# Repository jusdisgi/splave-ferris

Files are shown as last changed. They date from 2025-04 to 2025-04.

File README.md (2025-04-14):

# splave-ferris
Simple 34-key split ergonomic keyboard running ZMK on a Seeed XIAO BLE controller and (eventually) supporting multiple switch types. Similar in layout to the Ferris Sweep except with a bit of finger splay.

My goals are to make the keyboard as small and thin as possibe while remaining comfortable, efficient, and relatively durable. That is the main rationale for not using hotswap switches; in addition to adding a bit of height, it makes the keys much less secure if you aren't using a case of some kind. I intend to plastidip the bottom and otherwise leave it raw.

The board is designed to be primarily assembled with SMD methods. I intend to use solder paste and a hotplate to surface mount the controller, button, switch, and all the diodes, leaving only the battery connector and keyswitches to manually solder. I may even experiment with doing those with a hot air rework station. In any case this is why the back is totatlly devoid of components.

At the moment I have only done the Choc v1 version, but I expect to have more soon. The layout is done in ergogen, so it's relatively easy to adapt as needed. The next switch implemented will likely be the new Kailh CPG1316S ultra-low profile scissor switch. In addition to being extremely low-profile, it is a surface-mount part; with an appropriate battery connector, I may be able to design it so it required no manual soldering at all.

I created a schematic, but while I believe it to be accurate, it is not connected to the PCB files in any way, as they were generated by ergogen.

I remain very new at all this stuff. So if you see something wrong, please let me know!






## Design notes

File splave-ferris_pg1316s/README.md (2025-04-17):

# splave-ferris_pg1316s
A version of splave-ferris using the new Kailh PG1316S Ultra-low-profile scissor switches.

For more on the splave-ferris generally, see the readme in the base directory.

There are quite a few changes from the choc version of the board. Here are the most notable I could think of:

1. Keycaps for these switches are 16x16mm, so I changed the spacing accordingly. Several other dimensions were changed as needed.
2. I changed the battery connector from a JST to a Molex Pico EZMate, which surface mounts and has a much lower profile.
3. I removed the reset button, as the XIAO has one built in and this is my most minimalist design.
4. Battery connector and power switch are in new positions.
5. I switched from SOD-123 diodes to SOD-323 due to the diode pocket on the PG1316 having only 1.2mm of headspace.
6. Everything on the board is surface mount, and nothing is on the back of the board. This one can be manufactured in a single hotplate run.
7. The routing is somewhat cleaner, despite the all-SMD design requiring a lot of vias. I think I'm getting better.

As with the choc version, this is intended to be used without a case.

I created a schematic, but while I believe it to be accurate, it is not connected to the PCB files in any way, as they were generated by ergogen. Also, the PCB files you likely want are the _left and _right versions...the one without a direction includes both halves of the board, but the nets are all the same to that may cause problems. It is also unrouted, although if you do wish to do the routing differently there are also unrouted versions of each half.

I have included production gerber files. I am planning on ordering them soon, but as yet they are untested.

I remain very new at all this stuff. So if you see something wrong, please let me know!

Here are some pics...






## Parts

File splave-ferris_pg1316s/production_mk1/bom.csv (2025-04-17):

Designator | Footprint | Quantity | Value | LCSC Part #
CONN1 | battery_connector_molex_pico_ezmate_1x02 | 1
D1, D10, D11, D12, D13, D14, D15, D16, D17, D2, D3, D4, D5, D6, D7, D8, D9 | D_SOD-323F | 17
MCU1 | xiao_smd | 1
S1, S10, S11, S12, S13, S14, S15, S16, S17, S2, S3, S4, S5, S6, S7, S8, S9 | PG1316S | 17
T1 | SPDT_C128955 | 1

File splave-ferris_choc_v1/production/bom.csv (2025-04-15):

Designator | Footprint | Quantity | Value | LCSC Part #
B1 | SW_TACT_ALPS_SKQGABE010 | 1
D1, D10, D11, D12, D13, D14, D15, D16, D17, D2, D3, D4, D5, D6, D7, D8, D9 | diode_tht_sod123 | 17
JST1 | battery_connector_jst_ph_2 | 1
MCU1 | xiao_smd | 1
T1 | SPDT_C128955 | 1

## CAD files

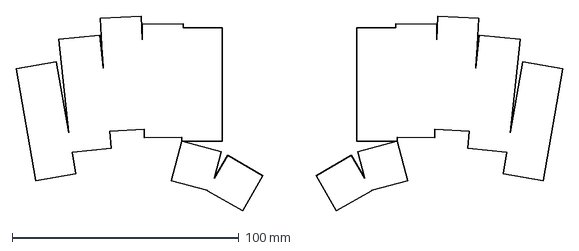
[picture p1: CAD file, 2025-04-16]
splave-ferris_pg1316s/output/outlines/raw.dxf
241.0 x 85.9 mm

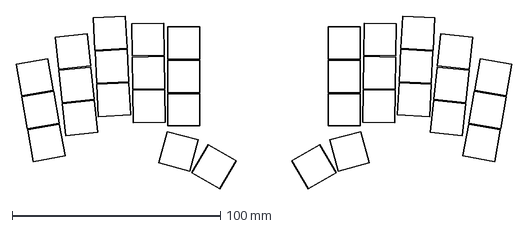
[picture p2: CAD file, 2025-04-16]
splave-ferris_pg1316s/output/outlines/keys.dxf
238.1 x 82.9 mm

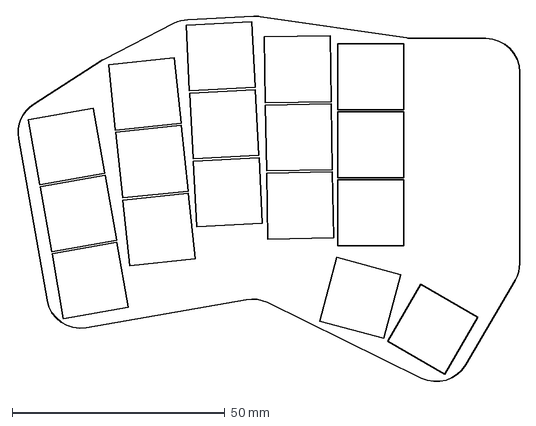
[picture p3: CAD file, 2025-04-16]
splave-ferris_pg1316s/output/outlines/combo.dxf
118.3 x 86.9 mm

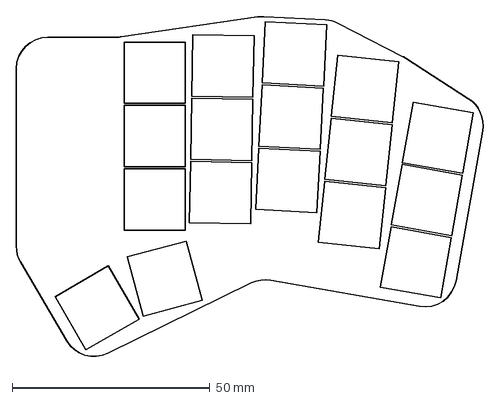
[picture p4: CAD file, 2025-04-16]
splave-ferris_pg1316s/output/outlines/combo_right.dxf
118.3 x 86.9 mm

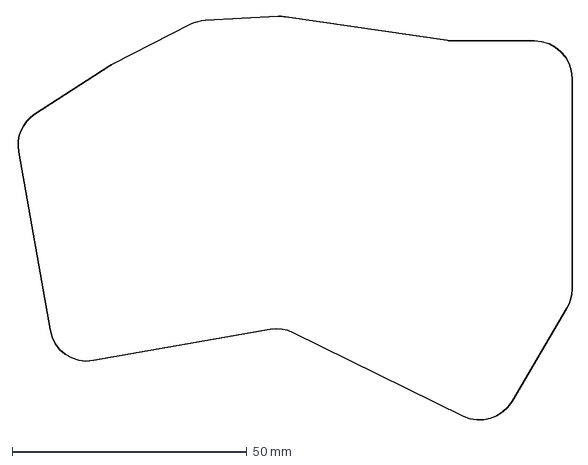
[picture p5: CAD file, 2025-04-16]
splave-ferris_pg1316s/output/outlines/board_left.dxf
118.3 x 86.9 mm

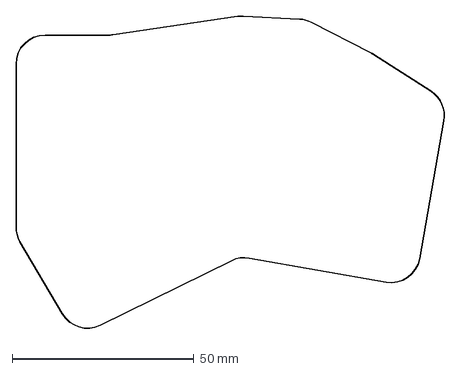
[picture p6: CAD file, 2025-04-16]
splave-ferris_pg1316s/output/outlines/board_right.dxf
118.3 x 86.9 mm

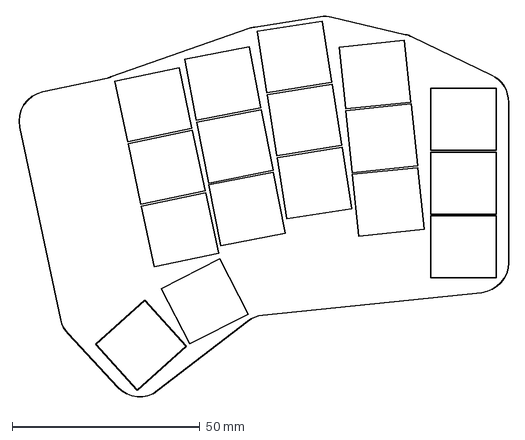
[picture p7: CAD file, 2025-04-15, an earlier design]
splave-ferris_choc_v1/output/outlines/combo_right.dxf
131.0 x 102.1 mm

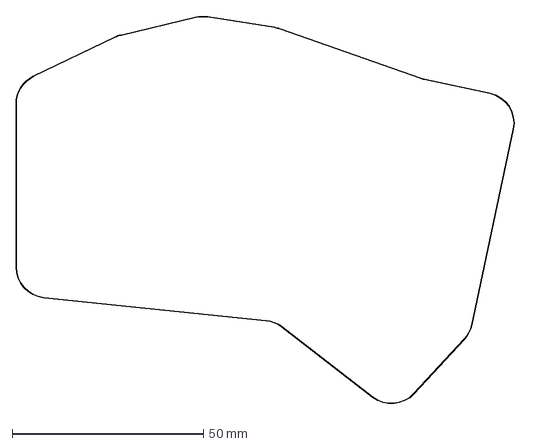
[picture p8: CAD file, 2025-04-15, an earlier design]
splave-ferris_choc_v1/output/outlines/board_left.dxf
131.0 x 102.1 mm

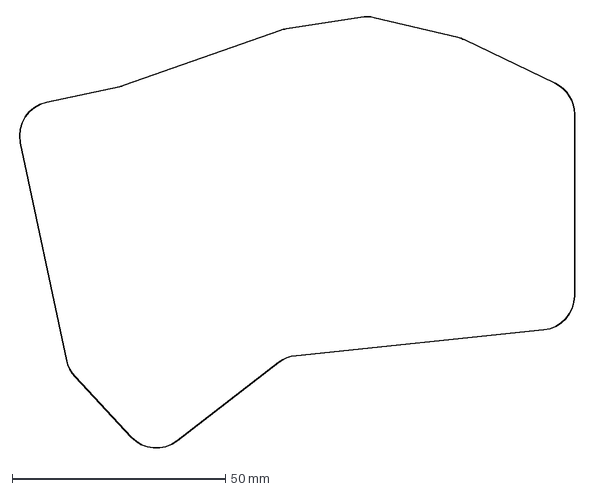
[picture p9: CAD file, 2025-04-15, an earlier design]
splave-ferris_choc_v1/output/outlines/board_right.dxf
131.0 x 102.1 mm

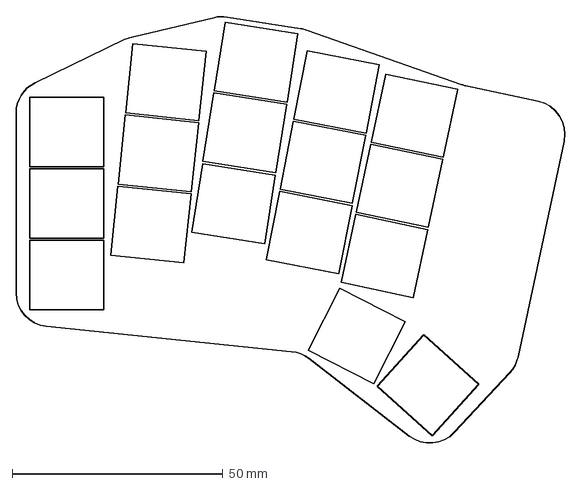
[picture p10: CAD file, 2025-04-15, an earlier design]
splave-ferris_choc_v1/output/outlines/combo.dxf
131.0 x 102.1 mm

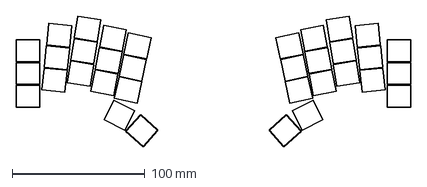
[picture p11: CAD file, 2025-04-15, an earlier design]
splave-ferris_choc_v1/output/outlines/keys.dxf
297.0 x 98.2 mm

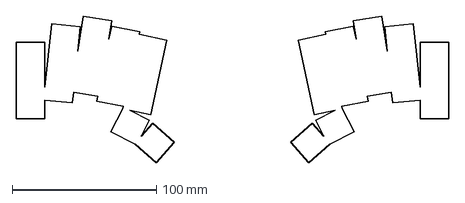
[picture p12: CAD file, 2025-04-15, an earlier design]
splave-ferris_choc_v1/output/outlines/raw.dxf
299.5 x 101.4 mm

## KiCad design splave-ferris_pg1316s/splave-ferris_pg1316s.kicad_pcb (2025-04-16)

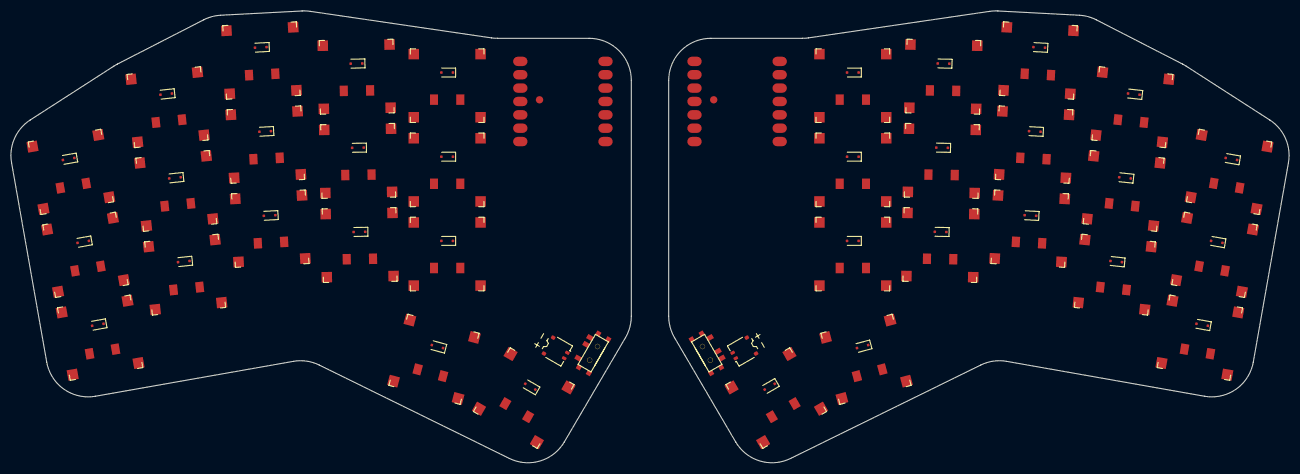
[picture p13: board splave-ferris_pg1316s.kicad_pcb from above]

Board: 2 copper layers, 242.9 x 85.9 mm, 74 parts (0 on the bottom side), 55 nets, no tracks yet.

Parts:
CONN1, CONN2: battery_connector_molex_pico_ezmate_1x02
D1, D2, D3, D4, D5, D6, D7, D8, D9, D10, D11, D12, D13, D14, D15, D16, D17, D18, D19, D20, D21, D22, D23, D24, D25, D26, D27, D28, D29, D30, D31, D32, D33, D34: D_SOD-323F
MCU1, MCU2: xiao_smd
S1, S2, S3, S4, S5, S6, S7, S8, S9, S10, S11, S12, S13, S14, S15, S16, S17, S18, S19, S20, S21, S22, S23, S24, S25, S26, S27, S28, S29, S30, S31, S32, S33, S34: PG1316S
T1, T2: SPDT_C128955

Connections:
BAT: MCU1.19, MCU2.19, T1.2, T2.1
BAT_P: CONN1.2, CONN2.2, T1.1, T2.2
CLK: MCU1.15, MCU2.15
D0: D3.2, D6.2, D9.2, D12.2, D15.2, D33.2, D34.2, MCU1.1, MCU2.1
D1: MCU1.2, MCU2.2, S7.2, S8.2, S9.2, S30.2, S31.2, S32.2, S34.2
D2: D2.2, D5.2, D8.2, D11.2, D14.2, MCU1.3, MCU2.3, S27.2, S28.2, S29.2, S33.2
D3: MCU1.4, MCU2.4, S4.2, S5.2, S6.2, S18.2, S19.2, S20.2
D4: D1.2, D4.2, D7.2, D10.2, D13.2, D18.2, D21.2, D24.2, D27.2, D30.2, MCU1.5, MCU2.5
D5: MCU1.6, MCU2.6, S1.2, S2.2, S3.2, S21.2, S22.2, S23.2
D6: MCU1.7, MCU2.7
D7: MCU1.8, MCU2.8
D8: D19.2, D22.2, D25.2, D28.2, D31.2, MCU1.9, MCU2.9, S10.2, S11.2, S12.2, S16.2
D9: D16.2, D17.2, MCU1.10, MCU2.10, S24.2, S25.2, S26.2
D10: D20.2, D23.2, D26.2, D29.2, D32.2, MCU1.11, MCU2.11, S13.2, S14.2, S15.2, S17.2
DIO: MCU1.16, MCU2.16
GND: CONN1.1, CONN2.1, MCU1.13, MCU1.18, MCU1.20, MCU2.13, MCU2.18, MCU2.20
NFC1: MCU1.21, MCU2.21
NFC2: MCU1.22, MCU2.22
RAW3V3: MCU1.12, MCU2.12
RAW5V: MCU1.14, MCU2.14
RST: MCU1.17, MCU2.17
far_fan: D17.1, S17.1
index_bottom: D10.1, S10.1
index_home: D11.1, S11.1
index_top: D12.1, S12.1
inner_bottom: D13.1, S13.1
inner_home: D14.1, S14.1
inner_top: D15.1, S15.1
middle_bottom: D7.1, S7.1
middle_home: D8.1, S8.1
middle_top: D9.1, S9.1
mirror_far_fan: D34.1, S34.1
mirror_index_bottom: D27.1, S27.1
mirror_index_home: D28.1, S28.1
mirror_index_top: D29.1, S29.1
mirror_inner_bottom: D30.1, S30.1
mirror_inner_home: D31.1, S31.1
mirror_inner_top: D32.1, S32.1
mirror_middle_bottom: D24.1, S24.1
mirror_middle_home: D25.1, S25.1
mirror_middle_top: D26.1, S26.1
mirror_near_fan: D33.1, S33.1
mirror_pinky_bottom: D18.1, S18.1
mirror_pinky_home: D19.1, S19.1
mirror_pinky_top: D20.1, S20.1
mirror_ring_bottom: D21.1, S21.1
mirror_ring_home: D22.1, S22.1
mirror_ring_top: D23.1, S23.1
near_fan: D16.1, S16.1
pinky_bottom: D1.1, S1.1
pinky_home: D2.1, S2.1
pinky_top: D3.1, S3.1
ring_bottom: D4.1, S4.1
ring_home: D5.1, S5.1
ring_top: D6.1, S6.1

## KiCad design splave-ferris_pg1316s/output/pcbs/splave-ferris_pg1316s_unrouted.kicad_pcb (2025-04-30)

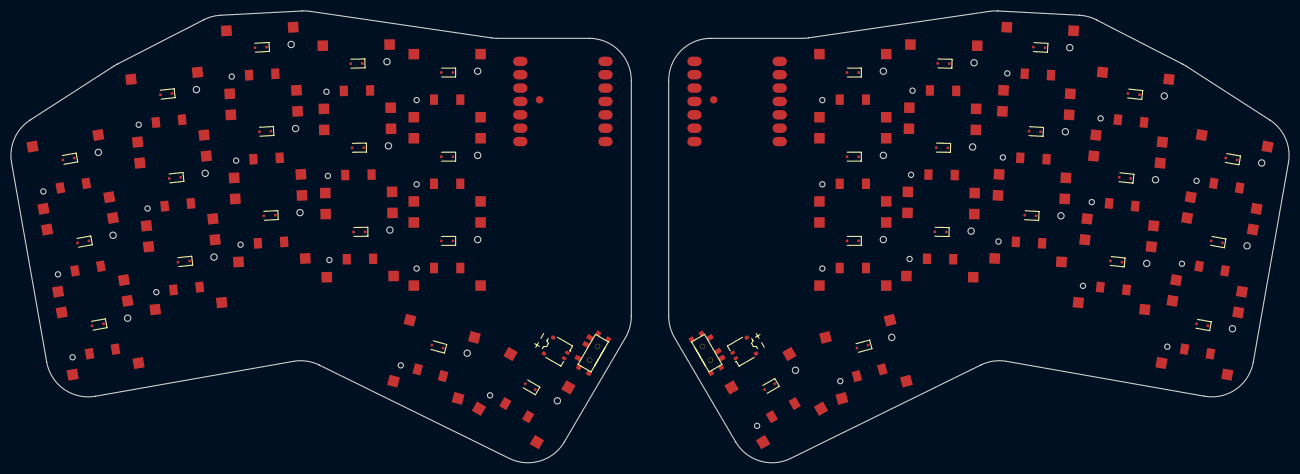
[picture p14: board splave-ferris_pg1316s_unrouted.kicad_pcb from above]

Board: 2 copper layers, 242.9 x 85.9 mm, 74 parts (0 on the bottom side), 55 nets, no tracks yet.

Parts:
CONN1, CONN2: battery_connector_molex_pico_ezmate_1x02
D1, D2, D3, D4, D5, D6, D7, D8, D9, D10, D11, D12, D13, D14, D15, D16, D17, D18, D19, D20, D21, D22, D23, D24, D25, D26, D27, D28, D29, D30, D31, D32, D33, D34: D_SOD-323F
MCU1, MCU2: xiao_smd
S1, S2, S3, S4, S5, S6, S7, S8, S9, S10, S11, S12, S13, S14, S15, S16, S17, S18, S19, S20, S21, S22, S23, S24, S25, S26, S27, S28, S29, S30, S31, S32, S33, S34: CPG1316S01D02_mikeholscher
T1, T2: SPDT_C128955

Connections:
BAT: MCU1.19, MCU2.19, T1.2, T2.1
BAT_P: CONN1.2, CONN2.2, T1.1, T2.2
CLK: MCU1.15, MCU2.15
D0: D3.1, D6.1, D9.1, D12.1, D15.1, D33.1, D34.1, MCU1.1, MCU2.1
D1: MCU1.2, MCU2.2, S7.2, S8.2, S9.2, S30.2, S31.2, S32.2, S34.2
D2: D2.1, D5.1, D8.1, D11.1, D14.1, MCU1.3, MCU2.3, S27.2, S28.2, S29.2, S33.2
D3: MCU1.4, MCU2.4, S4.2, S5.2, S6.2, S18.2, S19.2, S20.2
D4: D1.1, D4.1, D7.1, D10.1, D13.1, D18.1, D21.1, D24.1, D27.1, D30.1, MCU1.5, MCU2.5
D5: MCU1.6, MCU2.6, S1.2, S2.2, S3.2, S21.2, S22.2, S23.2
D6: MCU1.7, MCU2.7
D7: MCU1.8, MCU2.8
D8: D19.1, D22.1, D25.1, D28.1, D31.1, MCU1.9, MCU2.9, S10.2, S11.2, S12.2, S16.2
D9: D16.1, D17.1, MCU1.10, MCU2.10, S24.2, S25.2, S26.2
D10: D20.1, D23.1, D26.1, D29.1, D32.1, MCU1.11, MCU2.11, S13.2, S14.2, S15.2, S17.2
DIO: MCU1.16, MCU2.16
GND: CONN1.1, CONN2.1, MCU1.13, MCU1.18, MCU1.20, MCU2.13, MCU2.18, MCU2.20
NFC1: MCU1.21, MCU2.21
NFC2: MCU1.22, MCU2.22
RAW3V3: MCU1.12, MCU2.12
RAW5V: MCU1.14, MCU2.14
RST: MCU1.17, MCU2.17
far_fan: D17.2, S17.1
index_bottom: D10.2, S10.1
index_home: D11.2, S11.1
index_top: D12.2, S12.1
inner_bottom: D13.2, S13.1
inner_home: D14.2, S14.1
inner_top: D15.2, S15.1
middle_bottom: D7.2, S7.1
middle_home: D8.2, S8.1
middle_top: D9.2, S9.1
mirror_far_fan: D34.2, S34.1
mirror_index_bottom: D27.2, S27.1
mirror_index_home: D28.2, S28.1
mirror_index_top: D29.2, S29.1
mirror_inner_bottom: D30.2, S30.1
mirror_inner_home: D31.2, S31.1
mirror_inner_top: D32.2, S32.1
mirror_middle_bottom: D24.2, S24.1
mirror_middle_home: D25.2, S25.1
mirror_middle_top: D26.2, S26.1
mirror_near_fan: D33.2, S33.1
mirror_pinky_bottom: D18.2, S18.1
mirror_pinky_home: D19.2, S19.1
mirror_pinky_top: D20.2, S20.1
mirror_ring_bottom: D21.2, S21.1
mirror_ring_home: D22.2, S22.1
mirror_ring_top: D23.2, S23.1
near_fan: D16.2, S16.1
pinky_bottom: D1.2, S1.1
pinky_home: D2.2, S2.1
pinky_top: D3.2, S3.1
ring_bottom: D4.2, S4.1
ring_home: D5.2, S5.1
ring_top: D6.2, S6.1

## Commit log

2025-04-14 Initial upload of Ergogen and KiCad assets. Complete choc v1, very early PG1316S work.
    [board_left.dxf, board_right.dxf, combo.dxf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]
2025-04-15 Finalized choc_v1 design and created production files.
    [board_left.dxf, board_right.dxf, bom.csv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]
2025-04-16 Add PG1316S version including schematics, PCB files, and ergogen config/footprints.
    [board_left.dxf, board_right.dxf, combo.dxf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]
2025-04-16 Delete splave-ferris_cpg1316s directory
    This was replaced by the pg1316s directory once I figured out how to get that switch working as an ergogen footprint.
    [splave-ferris_cpg1316s.kicad_pcb, splave-ferris_cpg1316s.kicad_sch, splave-ferris_cpg1316s_left.kicad_pcb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]
2025-04-17 Complete routing for PG1316S variant, create production files.
    [bom.csv, designators.csv, positions.csv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]
2025-04-18 Add multidiode package footprints.
2025-04-30 Add stablizer holes to PG1316S footprint, regenerate PCB files.
    [bom.csv, designators.csv, positions.csv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]
2025-04-30 Add comments to new footprint file.
